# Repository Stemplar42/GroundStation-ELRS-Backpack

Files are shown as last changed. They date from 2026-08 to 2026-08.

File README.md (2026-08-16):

# GroundStation ELRS Backpack

**GroundStation ELRS Backpack** es una estación de tierra portátil basada en ESP32 para recibir y visualizar telemetría CRSF (Crossfire) desde un módulo **ExpressLRS TX Backpack** mediante WiFi/UDP.

La versión incluida en este repositorio corresponde a:

- Firmware: **GroundStation V2.5.1 Professional Stable Release**
- Release pública sugerida: **v1.0.0 Stable**
- Plataforma: **ESP32 NodeMCU 38 pines USB-C**
- Pantalla: **TFT ST7789 1,9 pulgadas, 172 x 320 píxeles**
- Autor del proyecto: **Ing. Marcelo Grippo**

GroundStation logo

## Estado del proyecto

Esta versión fue validada en hardware real con alimentación autónoma mediante una batería 18650, TP4056 y Step Down regulado a **3,30 V exactos** hacia el pin **3.3V** de la ESP32.

## Funciones principales

- Conexión automática al primer SSID visible que comience con `ExpressLRS TX Backpack xxxxxx` y luego cualquier número.
- Recepción UDP local en puerto `14550`.
- Decodificación de tramas MSPv2 y CRSF.
- Visualización de telemetría en pantalla TFT ST7789.
- Interfaz de 5 pantallas: GENERAL, HORIZONTE, ENERGIA, GPS y DEBUG.
- Horizonte artificial con pitch, roll, heading, altitud y velocidad.
- HOME automático al salir del modo `WAIT`.
- Flecha HOME tipo OSD y distancia al HOME.
- GPS con pantalla normal y modo RECOVERY.
- Código QR de recuperación hacia Google Maps cuando hay pérdida de telemetría.
- Plus Code de recuperación.
- Detección automática de cantidad de celdas de batería.
- Color por tensión por celda.
- Control de brillo PWM en GPIO `25`.
- Barra de brillo en pantalla mediante pulsación larga de NEXT.
- Botón RESET físico conectado entre EN y GND.

## Hardware principal

- ESP32 NodeMCU 38 pines USB-C.
- TFT ST7789 1,9 pulgadas 172 x 320.
- Batería Li-Ion 18650.
- Porta batería 18650.
- Módulo TP4056 con protección.
- Step Down ajustable regulado a 3,30 V.
- Interruptor general.
- Pulsadores momentáneos para NEXT, PREV y RESET.
- Gabinete impreso en 3D.

## Archivos STL del gabinete

La Release v1.0.0 documenta el gabinete final **Case V18 SMOOTH_NO_REAR_LIP**.

Los archivos STL oficiales son:

```text
stl/GroundStation_Case_Body_v18_SMOOTH_NO_REAR_LIP.stl
stl/GroundStation_Case_RearCover_v18_SMOOTH_NO_REAR_LIP.stl
```

## Conexión rápida

### Pantalla TFT ST7789

| Señal TFT | GPIO ESP32 |
|---|---:|
| MOSI / SDA | GPIO23 |
| SCLK / SCL | GPIO18 |
| CS | GPIO5 |
| DC | GPIO2 |
| RST| GPIO4|
| BL / LED | GPIO25 |
| VCC | 3.3V |
| GND | GND  |

### Botones

| Función | Conexión |
|---|---|
| PREV / ANT | GPIO32 a GND, usando `INPUT_PULLUP` |
| NEXT | GPIO33 a GND, usando `INPUT_PULLUP` |
| RESET | EN a GND mediante pulsador momentáneo |

## Alimentación recomendada

No conectar una batería 18650 directamente al pin 3.3V de la ESP32.

Conexión validada:

```text
Batería 18650 -> TP4056 -> Step Down 3,30 V -> pin 3.3V ESP32
GND común entre TP4056, Step Down, ESP32 y TFT
```

Antes de conectar la placa, ajustar la salida del Step Down con multímetro a **3,30 V exactos**.

## Instalación del firmware

1. Instalar Arduino IDE.
2. Instalar soporte para placas ESP32.
3. Instalar las librerías indicadas en `docs/04_Firmware_Setup.md`.
4. Copiar `libraries_modified/TFT_eSPI/User_Setup.h` dentro de la librería TFT_eSPI instalada.
5. Abrir `firmware/GroundStation_V2_5_1_Professional_Stable/GroundStation_V2_5_1_Professional_Stable.ino`.
6. Seleccionar la placa ESP32 correspondiente.
7. Compilar y cargar.

## Uso básico

1. Encender la GroundStation.
2. Encender el módulo ExpressLRS TX Backpack de la radio en modo WiFi.
3. Esperar que la estación encuentre el SSID `ExpressLRS TX Backpack xxxx*`.
4. Esperar recepción UDP y luego telemetría del avión (recién allí conecte el modelo).
5. Usar NEXT y PREV para navegar entre pantallas.
6. Mantener NEXT para abrir el control de brillo.
7. Usar RESET si es necesario reiniciar la ESP32.

## Documentación

- [Descripción general](docs/01_Overview.md)
- [Hardware](docs/02_Hardware.md)
- [Conexionado](docs/03_Wiring.md)
- [Instalación del firmware](docs/04_Firmware_Setup.md)
- [Manual de uso](docs/05_User_Manual.md)
- [Pantallas](docs/06_Display_Screens.md)
- [Sistema de alimentación](docs/07_Power_System.md)
- [Gabinete 3D](docs/08_3D_Case.md)
- [Solución de problemas](docs/09_Troubleshooting.md)

## Advertencia

Este proyecto es experimental y está orientado a uso maker, educativo y FPV recreativo. Verificar siempre alimentación, polaridad, cableado y estabilidad antes de utilizarlo en campo.

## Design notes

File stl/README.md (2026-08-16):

# STL files - GroundStation Case V18

The final case design for Release v1.0.0 uses the following STL files:

- `GroundStation_Case_Body_v18_SMOOTH_NO_REAR_LIP.stl`
- `GroundStation_Case_RearCover_v18_SMOOTH_NO_REAR_LIP.stl`

These STL files are not embedded in this documentation package because the chat platform did not allow uploading `.stl` or `.zip` files in the source conversation.

Before publishing the GitHub release, manually copy the two final STL files into this `stl/` folder using the exact filenames above.

## Case version

- Case version: V18
- Design variant: SMOOTH_NO_REAR_LIP
- Product release: GroundStation ELRS Backpack v1.0.0 Stable
- Firmware reference: GroundStation V2.5.1 Professional Stable Release

## Intended internal components

- ESP32 NodeMCU 38 pins USB-C
- TFT ST7789 1.9 inch display
- 18650 battery holder
- TP4056 charger module
- Step Down regulator adjusted to 3.30 V
- Main power switch
- NEXT and PREV buttons
- Physical RESET button between EN and GND

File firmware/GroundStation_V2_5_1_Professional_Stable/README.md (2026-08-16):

Firmware GroundStation V2.5.1 Professional Stable Release

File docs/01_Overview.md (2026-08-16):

<!-- GroundStation ELRS Backpack documentation -->

# 01 - Descripción general

GroundStation ELRS Backpack es una estación de tierra portátil basada en ESP32, pensada para visualizar telemetría recibida desde un módulo ExpressLRS TX Backpack.

El firmware incluido corresponde a GroundStation V2.5.1 Professional Stable Release. El sketch declara conexión WiFi contra SSID que comienzan con `ExpressLRS TX Backpack`, contraseña `expresslrs`, recepción UDP local en puerto 14550 y parser de datos MSPv2/CRSF.

## Objetivos del proyecto

- Construir una estación compacta y autónoma.
- Visualizar datos críticos de telemetría en campo.
- Mantener última posición GPS válida para recuperación.
- Ofrecer navegación por pantallas con botones físicos.
- Permitir brillo regulable para uso en exterior.
- Facilitar replicación por otros usuarios mediante documentación y archivos de firmware.

## Arquitectura general

```text
ExpressLRS TX Backpack -> WiFi -> ESP32 -> UDP 14550 -> Parser MSPv2/CRSF -> TFT ST7789
```

## Pantallas disponibles

1. GENERAL
2. HORIZONTE
3. ENERGIA
4. GPS / RECOVERY
5. DEBUG

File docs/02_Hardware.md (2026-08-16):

<!-- GroundStation ELRS Backpack documentation -->

# 02 - Hardware

## Componentes principales

- ESP32 NodeMCU 38 pines USB-C.
- Pantalla TFT ST7789 1,9 pulgadas, 172 x 320 píxeles.
- Batería Li-Ion 18650.
- Porta batería 18650.
- Módulo TP4056 con protección.
- Step Down ajustable.
- Interruptor general.
- Pulsadores momentáneos.
- Gabinete impreso en 3D.

## Pines principales extraídos del firmware

| Elemento | GPIO |
|---|---:|
| BTN_PREV | GPIO32 |
| BTN_NEXT | GPIO33 |
| Backlight PWM | GPIO25 |
| TFT MOSI | GPIO23 |
| TFT SCLK | GPIO18 |
| TFT CS | GPIO5 |
| TFT DC | GPIO2 |
| TFT RST | GPIO4 |

## Observaciones

Los botones usan `INPUT_PULLUP`, por lo tanto cada pulsador debe cerrar contra GND.

El botón RESET no está programado en el sketch porque actúa físicamente entre EN y GND.

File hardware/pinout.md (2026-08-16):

# Pinout GroundStation ELRS Backpack

## TFT ST7789

| Función | GPIO |
|---|---:|
| MOSI / SDA | GPIO23 |
| SCLK / SCL | GPIO18 |
| CS | GPIO5 |
| DC | GPIO2 |
| RST | GPIO4 |
| BL / LED / BLK | GPIO25 |

## Botones

| Función | GPIO / conexión |
|---|---|
| PREV / ANT | GPIO32 a GND |
| NEXT | GPIO33 a GND |
| RESET | EN a GND |

## Alimentación

| Señal | Conexión |
|---|---|
| +3,30 V regulados | Pin 3.3V ESP32 |
| GND | GND ESP32 |
| VCC TFT | 3.3V |
| GND TFT | GND común |

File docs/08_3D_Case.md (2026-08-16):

<!-- GroundStation ELRS Backpack documentation -->

# 08 - Gabinete 3D

## Archivos STL oficiales

La versión final del gabinete documentada para la Release v1.0.0 es:

```text
stl/
├── GroundStation_Case_Body_v18_SMOOTH_NO_REAR_LIP.stl
└── GroundStation_Case_RearCover_v18_SMOOTH_NO_REAR_LIP.stl
```

## Estado del diseño 3D

- Versión del gabinete: **V18**.
- Variante: **SMOOTH_NO_REAR_LIP**.
- Release del producto: **GroundStation ELRS Backpack v1.0.0 Stable**.
- Firmware asociado: **GroundStation V2.5.1 Professional Stable Release**.

## Filosofía de diseño

- Gabinete compacto para uso de campo.
- Diseño pensado para montaje sin tornillos.
- Fijación interna de módulos con silicona caliente.
- Tapa trasera independiente.
- Versión sin reborde posterior, indicada por `NO_REAR_LIP`.
- Acabado suavizado, indicado por `SMOOTH`.
- Pantalla frontal protegida por el propio cuerpo del gabinete.
- Espacio interno para electrónica, batería y módulos de alimentación.

## Módulos internos previstos

- ESP32 NodeMCU 38 pines USB-C.
- Pantalla TFT ST7789 de 1,9 pulgadas.
- Porta batería 18650.
- TP4056.
- Step Down regulado a 3,30 V.
- Interruptor rectangular.
- Pulsadores externos NEXT y PREV.
- Pulsador RESET físico.

## Recomendación de carpeta GitHub

Los STL finales deben ubicarse en la carpeta `stl/` del repositorio con los nombres exactos indicados arriba.

## Parámetros de impresión sugeridos

Estos valores son una base recomendada para PLA/PLA+. Pueden ajustarse según impresora, filamento y resultado buscado.

| Parámetro | Recomendación |
|---|---|
| Material | PLA o PLA+ |
| Boquilla | 0,4 mm |
| Altura de capa | 0,20 mm |
| Perímetros | 3 |
| Relleno | 15 % a 25 % |
| Patrón de relleno | Gyroid o Grid |
| Adhesión | Brim si hay riesgo de despegue |
| Soportes | Revisar en slicer según orientación elegida |
| Impresora validada por el proyecto | Artillery Sidewinder X2 |

## Orientación de impresión

La orientación debe verificarse visualmente en Cura o en el slicer utilizado. Para el cuerpo principal conviene priorizar:

- buena adherencia a la cama,
- mínima cantidad de soportes,
- buen acabado del frente de pantalla,
- resistencia adecuada en paredes y esquinas.

## Montaje recomendado

1. Imprimir el cuerpo principal y la tapa trasera.
2. Presentar la pantalla TFT en el frente antes de pegar.
3. Presentar ESP32, TP4056, Step Down y porta batería 18650.
4. Verificar acceso a conectores USB necesarios.
5. Verificar que los pulsadores accionen correctamente.
6. Fijar módulos con silicona caliente.
7. Verificar alimentación a 3,30 V antes de cerrar.
8. Cerrar la tapa trasera con silicona caliente si se desea mantener el diseño sin tornillos.

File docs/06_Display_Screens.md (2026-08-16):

<!-- GroundStation ELRS Backpack documentation -->

# 06 - Pantallas del sistema

## Pantalla de arranque

El firmware muestra una pantalla de sistema con el título `GROUND STATION`, estado `BOOTING...` y descripción `ESP32 + TFT + BACKPACK`.

## Pantalla GENERAL

Muestra modo de vuelo, tensión de batería, porcentaje de batería, LQ, SNR y satélites.

## Pantalla HORIZONTE

Muestra horizonte artificial, pitch, roll, altitud GPS, velocidad, heading, tensión de batería, flecha HOME, distancia a HOME y mini brújula.

## Pantalla ENERGIA

Muestra tensión total, detección automática de celdas, tensión por celda, corriente, consumo mAh, porcentaje INAV y potencia RF interpretada.

## Pantalla GPS

En modo normal muestra coordenadas, satélites, altitud, velocidad, heading y datos HOME.

En modo RECOVERY muestra última posición GPS válida, altitud, Plus Code y QR a Google Maps.

## Pantalla DEBUG

Muestra contadores UDP, MSPv2, CRSF, tramas AIR, paquetes desconocidos, edad de datos UDP/TEL, LQ, estado HOME, estado GPS, RF e IP local.

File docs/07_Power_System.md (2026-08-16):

<!-- GroundStation ELRS Backpack documentation -->

# 07 - Sistema de alimentación

## Esquema validado

```text
Batería 18650 -> TP4056 -> Step Down -> 3,30 V -> pin 3.3V ESP32
```

## Punto crítico

La salida del Step Down debe ajustarse con multímetro antes de conectar la ESP32. El valor validado es **3,30 V exactos**.

## Advertencias

- No conectar una batería 18650 directamente al pin 3.3V.
- Una batería 18650 completamente cargada puede estar cerca de 4,2 V.
- El pin 3.3V debe recibir una tensión regulada y estable.
- Todos los módulos deben compartir GND.
- Verificar polaridad antes de energizar.

## Recomendación de montaje

Ajustar inicialmente el Step Down sin carga, medir, conectar la ESP32, volver a medir durante funcionamiento y verificar que la tensión se mantenga estable con WiFi y TFT encendidos.

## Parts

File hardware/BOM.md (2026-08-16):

# BOM - Lista de materiales

| Ítem | Descripción | Cantidad | Observaciones |
|---|---|---:|---|
| ESP32 | NodeMCU ESP32 38 pines USB-C | 1 | Placa principal |
| Pantalla | TFT ST7789 1,9 pulgadas 172 x 320 | 1 | Display principal |
| Batería | Li-Ion 18650 | 1 | Alimentación portátil |
| Porta batería | Porta celda 18650 | 1 | Montaje interno |
| Cargador | TP4056 con protección | 1 | Carga de batería |
| Regulador | Step Down ajustable | 1 | Ajustar a 3,30 V |
| Interruptor | Interruptor rectangular con uñas | 1 | Encendido general |
| Pulsador NEXT | Pulsador momentáneo | 1 | GPIO33 a GND |
| Pulsador PREV | Pulsador momentáneo | 1 | GPIO32 a GND |
| Pulsador RESET | Pulsador momentáneo | 1 | EN a GND |
| Cableado | Cable fino flexible | varios | Conexiones internas |
| Gabinete | Impresión 3D | 1 set | Body + tapa |

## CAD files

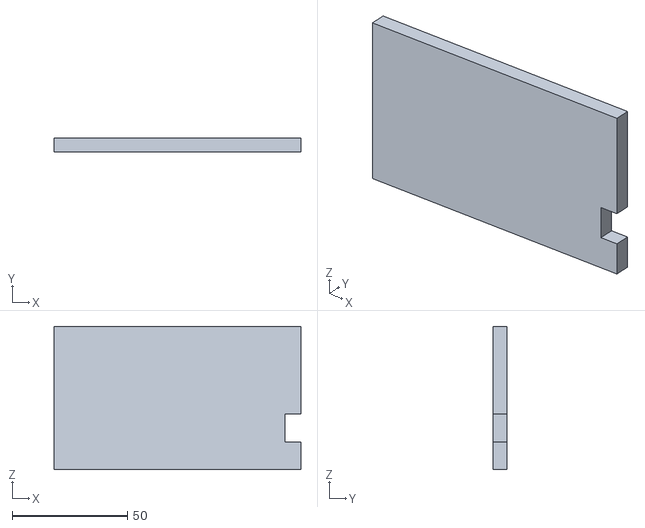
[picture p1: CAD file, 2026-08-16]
stl/GroundStation_Case_RearCover_v18_SMOOTH_NO_REAR_LIP.stl
107.0 x 6.00 x 62.0

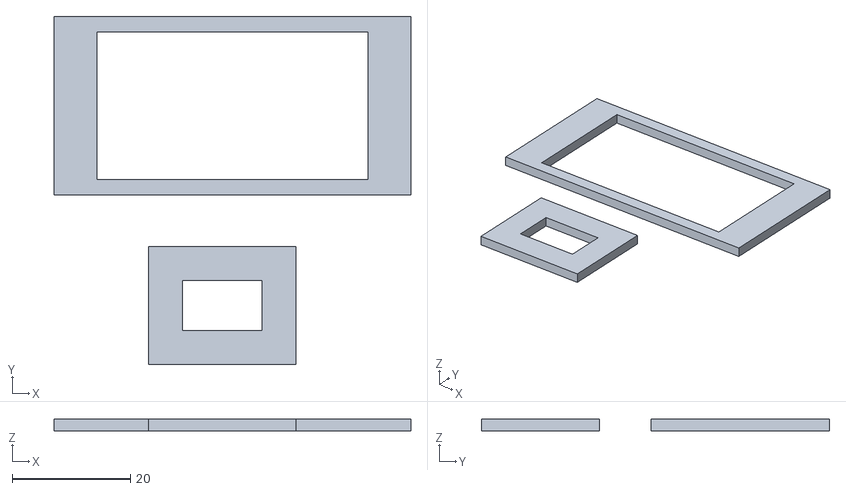
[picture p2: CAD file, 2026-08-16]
stl/Marco_ONOFF.stl
60.5 x 59.0 x 2.00

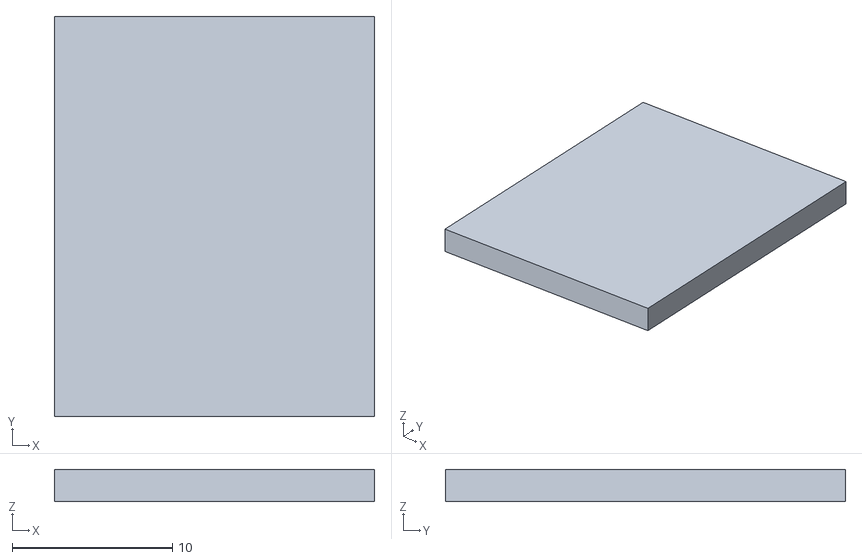
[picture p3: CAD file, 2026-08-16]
stl/Apoyo_TP4056.stl
20.0 x 25.0 x 2.00

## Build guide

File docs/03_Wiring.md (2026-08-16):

<!-- GroundStation ELRS Backpack documentation -->

# 03 - Conexionado

## Alimentación

```text
Batería 18650 positivo -> B+ TP4056
Batería 18650 negativo -> B- TP4056
OUT+ TP4056 -> entrada positiva Step Down
OUT- TP4056 -> entrada negativa Step Down
Salida Step Down +3,30 V -> pin 3.3V ESP32
Salida Step Down GND -> GND ESP32
GND común -> TFT, botones y módulos
```

## Pantalla TFT ST7789

| Pin pantalla | Conectar a ESP32 |
|---|---:|
| VCC | 3.3V |
| GND | GND |
| MOSI / SDA | GPIO23 |
| SCK / SCL | GPIO18 |
| CS | GPIO5 |
| DC | GPIO2 |
| RST | GPIO4 |
| BL / LED / BLK | GPIO25 |

## Botones

| Botón | Conexión |
|---|---|
| PREV / ANT | GPIO32 a GND |
| NEXT | GPIO33 a GND |
| RESET | EN a GND |

## Plano lógico ASCII

```text
                 +-------------------------+
                 |       ESP32 NodeMCU     |
                 |                         |
TFT MOSI --------| GPIO23                  |
TFT SCLK --------| GPIO18                  |
TFT CS ----------| GPIO5                   |
TFT DC ----------| GPIO2                   |
TFT RST ---------| GPIO4                   |
TFT BL ----------| GPIO25 PWM              |
PREV ------------| GPIO32 -> pulsador -> GND |
NEXT ------------| GPIO33 -> pulsador -> GND |
RESET -----------| EN -> pulsador -> GND   |
3.30 V ----------| 3.3V                    |
GND -------------| GND                     |
                 +-------------------------+
```

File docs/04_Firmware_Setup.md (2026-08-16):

<!-- GroundStation ELRS Backpack documentation -->

# 04 - Instalación del firmware

## Librerías utilizadas por el sketch

El sketch incluye las siguientes librerías:

- `WiFi.h`
- `WiFiUdp.h`
- `TFT_eSPI.h`
- `Preferences.h`
- `math.h`
- `qrcode.h`

## Instalación recomendada

1. Instalar Arduino IDE.
2. Instalar soporte para ESP32 desde el gestor de placas.
3. Instalar la librería TFT_eSPI.
4. Instalar o disponer de la librería `qrcode.h` compatible con ESP32.
5. Copiar `libraries_modified/TFT_eSPI/User_Setup.h` sobre el `User_Setup.h` de la librería TFT_eSPI instalada.
6. Abrir el archivo `.ino` incluido en la carpeta `firmware`.
7. Seleccionar la placa ESP32 correspondiente.
8. Compilar.
9. Cargar el firmware.

## Configuración TFT_eSPI incluida

- Driver: ST7789.
- Resolución: 172 x 320.
- MOSI: GPIO23.
- SCLK: GPIO18.
- CS: GPIO5.
- DC: GPIO2.
- RST: GPIO4.
- Frecuencia SPI: 27 MHz.

## Configuración WiFi/UDP del firmware

- Prefijo SSID: `ExpressLRS TX Backpack`.
- Contraseña: `expresslrs`.
- Puerto UDP local: `14550`.
- Timeout UDP: `2000` ms.
- Timeout telemetría de aeronave: `2000` ms.

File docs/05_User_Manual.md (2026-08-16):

<!-- GroundStation ELRS Backpack documentation -->

# 05 - Manual de uso

## Encendido

1. Colocar una batería 18650 cargada.
2. Encender el interruptor principal.
3. Confirmar que aparece la pantalla de arranque `GROUND STATION`.
4. Encender el sistema ExpressLRS TX Backpack.
5. Esperar conexión WiFi.
6. Esperar recepción UDP.
7. Esperar telemetría de aeronave.

## Navegación

| Acción | Resultado |
|---|---|
| Pulsar NEXT | Avanza a la pantalla siguiente |
| Pulsar PREV | Retrocede a la pantalla anterior |
| Mantener NEXT | Abre barra de brillo |
| NEXT en modo brillo | Sube brillo |
| PREV en modo brillo | Baja brillo |
| RESET físico | Reinicia la ESP32 |

## Niveles de brillo

El firmware define cuatro niveles PWM:

- 25 por ciento
- 50 por ciento
- 75 por ciento
- 100 por ciento

El nivel se guarda usando `Preferences`, por lo que se conserva entre reinicios.

## Estados de enlace

| Estado | Significado |
|---|---|
| LIVE | UDP y telemetría de aeronave activos |
| UDP LOST | No se reciben paquetes UDP dentro del timeout |
| TEL LOST | Hay UDP, pero no telemetría útil de la aeronave |

## Modo RECOVERY

La pantalla GPS pasa a modo RECOVERY cuando se detecta pérdida UDP o pérdida de telemetría. Si existe una última posición GPS válida, muestra coordenadas, altitud, Plus Code y QR hacia Google Maps.

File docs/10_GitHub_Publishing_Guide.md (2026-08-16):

# 10 - Guía rápida de publicación en GitHub

## Nombre sugerido del repositorio

`GroundStation-ELRS-Backpack`

## Descripción sugerida

Portable ESP32 Ground Station for ExpressLRS Backpack Telemetry.

## Antes de publicar

Verificar que estén presentes:

- `README.md`
- `CHANGELOG.md`
- `LICENSE`
- `firmware/GroundStation_V2_5_1_Professional_Stable/GroundStation_V2_5_1_Professional_Stable.ino`
- `libraries_modified/TFT_eSPI/User_Setup.h`
- `hardware/BOM.md`
- `hardware/pinout.md`
- `docs/`
- `assets/logo/groundstation_logo.svg`
- `stl/GroundStation_Case_Body_v18_SMOOTH_NO_REAR_LIP.stl`
- `stl/GroundStation_Case_RearCover_v18_SMOOTH_NO_REAR_LIP.stl`

## Release

- Tag: `v1.0.0`
- Title: `GroundStation V2.5.1 Professional Stable Release`
- Release text: copiar desde `release/GitHub_Release_Text_v1.0.0.txt`

## Recomendación

Adjuntar también este paquete ZIP como asset de la release.

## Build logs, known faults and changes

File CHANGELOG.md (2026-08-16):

# Changelog

## v1.0.0 Stable - GroundStation V2.5.1 Professional Stable Release

Primera release pública estable del proyecto GroundStation ELRS Backpack.

### Añadido

- Recepción de telemetría ExpressLRS Backpack por WiFi/UDP.
- Conexión automática al primer SSID compatible `ExpressLRS TX Backpack*`.
- Decodificación de tramas MSPv2 y CRSF.
- Pantallas GENERAL, HORIZONTE, ENERGIA, GPS y DEBUG.
- Horizonte artificial con pitch, roll, escala de alabeo y referencia de aeronave.
- HOME automático al detectar modo de vuelo distinto de `WAIT` con GPS válido.
- Flecha HOME tipo OSD.
- Mini brújula.
- Pantalla GPS estilo instrumento con coordenadas, satélites, altitud, velocidad y rumbo.
- Modo RECOVERY con última posición GPS válida.
- QR de recuperación para Google Maps.
- Plus Code de recuperación.
- Detección automática de celdas 2S a 8S.
- Color por tensión por celda.
- Control de brillo PWM en backlight.
- Persistencia de brillo en memoria Preferences.
- Botón RESET físico por EN a GND.

### Corregido

- Brillo PWM corregido y estable.
- Barra de brillo con actualización en vivo.
- Reset físico sin necesidad de lógica adicional en firmware.
- Conservación de última posición GPS válida durante pérdida de telemetría.

### Validado

- ESP32 NodeMCU 38 pines USB-C.
- TFT ST7789 1,9 pulgadas 172 x 320.
- Alimentación por batería 18650 con Step Down ajustado a 3,30 V.
- Funcionamiento de navegación por botones y control de brillo.

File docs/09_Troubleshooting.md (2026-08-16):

<!-- GroundStation ELRS Backpack documentation -->

# 09 - Solución de problemas

## La ESP32 no enciende

- Comprobar batería 18650.
- Comprobar interruptor.
- Medir salida del Step Down.
- Confirmar 3,30 V en el pin 3.3V.
- Confirmar GND común.

## La pantalla no muestra imagen

- Verificar VCC y GND de la TFT.
- Verificar MOSI, SCLK, CS, DC y RST.
- Confirmar que la pantalla sea ST7789 172 x 320.
- Confirmar instalación correcta del `User_Setup.h` incluido.

## El brillo no cambia

- Verificar que BL/LED/BLK de la pantalla vaya a GPIO25.
- Verificar soldadura del pin de backlight.
- Mantener NEXT para abrir modo brillo.

## No conecta al Backpack

- Confirmar que el SSID comience con `ExpressLRS TX Backpack`.
- Confirmar contraseña `expresslrs`.
- Reiniciar Backpack y GroundStation.
- Acercar la estación al transmisor.

## UDP LOST

- Indica que no llegaron paquetes UDP dentro del timeout.
- Verificar WiFi y Backpack.

## TEL LOST

- Indica que hay UDP, pero no telemetría útil de aeronave dentro del timeout.
- Verificar que el avión transmita datos CRSF/MSPv2.

## Lecturas GPS nulas

- Esperar al menos 4 satélites.
- Verificar que el GPS del avión tenga fix.
- Verificar que la telemetría esté llegando correctamente.

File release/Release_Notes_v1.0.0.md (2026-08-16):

# Release v1.0.0 Stable

## GroundStation V2.5.1 Professional Stable Release

Primera publicación estable del proyecto GroundStation ELRS Backpack.

## Incluye

- Firmware Arduino IDE completo.
- Configuración TFT_eSPI adaptada a ST7789 172 x 320.
- Documentación de hardware.
- Pinout.
- Manual de usuario.
- Sistema de alimentación recomendado.
- Solución de problemas.
- Logo SVG del proyecto.

## Funciones destacadas

- Telemetría ELRS Backpack por WiFi/UDP.
- Parser MSPv2/CRSF.
- Horizonte artificial.
- HOME automático.
- GPS RECOVERY con QR.
- Control de brillo PWM.
- Botón RESET físico.
- Alimentación autónoma con 18650.

## Gabinete 3D incluido en la documentación

La release queda preparada para incluir los STL finales del gabinete:

- `GroundStation_Case_Body_v18_SMOOTH_NO_REAR_LIP.stl`
- `GroundStation_Case_RearCover_v18_SMOOTH_NO_REAR_LIP.stl`

Estos archivos corresponden al **Case V18 SMOOTH_NO_REAR_LIP**. Si los STL no están dentro del ZIP, copiarlos manualmente a la carpeta `stl/` antes de publicar en GitHub.

## Advertencia

Uso experimental. Verificar cableado, polaridad y alimentación antes de energizar.

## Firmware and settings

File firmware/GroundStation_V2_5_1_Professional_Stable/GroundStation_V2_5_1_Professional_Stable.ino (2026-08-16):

#include <WiFi.h>
#include <WiFiUdp.h>
#include <TFT_eSPI.h>
#include <Preferences.h>
#include <math.h>
#include <qrcode.h>

// =====================================================
// GROUND STATION V2.5.1
// ESP32 + ExpressLRS Backpack WiFi + CRSF + ST7789 TFT
// Base V2.4.2 recuperada + brillo PWM corregido + reset EN
// =====================================================
//
// Basada en GroundStation V2.1 validada.
// Cambios V2.3:
// - HOME automatico al salir de modo WAIT.
// - Distancia y rumbo al HOME.
// - Flecha HOME tipo OSD en pantalla Horizonte.
// - Altitud y velocidad en pantalla Horizonte.
// - Mini brujula N/E/S/W en pantalla Horizonte.
// - Pantalla POWER con deteccion automatica de celdas y V/Celda por color.
// - Pantalla GPS con estilo mas tipo Garmin.
// - Plus Code en pantalla RECOVERY.
// - QR de recuperacion solo en TEL LOST / UDP LOST.
// - Conexion automatica al primer SSID ExpressLRS TX Backpack visible.
// - QR compatible con libreria Espressif qrcode.h.
// - Brillo PWM en BLK por GPIO25.
// - Pulsacion larga NEXT abre barra de brillo.
// - En modo brillo: NEXT sube, PREV baja, barra actualiza en vivo.
// - Boton RESET dedicado: EN a GND.
// - No se modifica Core CRSF / UDP / Backpack / estados.
// =====================================================

// =====================================================
// WIFI BACKPACK
// =====================================================

const char* BACKPACK_PREFIX = "ExpressLRS TX Backpack";
const char* password = "expresslrs";

String selectedBackpackSsid = "";

WiFiUDP udp;

#define UDP_PORT_LOCAL 14550
#define TIMEOUT_UDP_MS 2000
#define TIMEOUT_AIRCRAFT_TELEM_MS 2000

// =====================================================
// BOTONES
// =====================================================

#define BTN_PREV 32
#define BTN_NEXT 33

// =====================================================
// BRILLO PWM / RESET
// =====================================================
// GPIO25 debe ir al pin BLK / BL / BACKLIGHT del TFT.
// El boton RESET fisico va entre EN y GND. No requiere codigo.

#define PIN_BL 25
#define BL_PWM_FREQ 5000
#define BL_PWM_RES 8
#define BL_PWM_CH 0

const uint8_t BRIGHTNESS_LEVELS[] = {64, 128, 192, 255};
const int BRIGHTNESS_COUNT = 4;
int brightnessIndex = 3;
uint32_t brightnessOverlayUntilMs = 0;
Preferences prefs;

// =====================================================
// TFT / SPRITE
// =====================================================

TFT_eSPI tft = TFT_eSPI();
TFT_eSprite spr = TFT_eSprite(&tft);

const int SCREEN_W = 320;
const int SCREEN_H = 172;

const int SPR_W = 320;
const int SPR_H = 172;

// Horizonte artificial
const int CX = 160;
const int CY = 92;
const int R  = 68;

const float PITCH_PIXELS_PER_DEG = 2.0;

// =====================================================
// PANTALLAS
// =====================================================

enum PantallaGS {
  P_GENERAL = 0,
  P_HORIZONTE = 1,
  P_ENERGIA = 2,
  P_GPS = 3,
  P_DEBUG = 4
};

const int TOTAL_PANTALLAS = 5;
int pantallaActual = P_GENERAL;

// =====================================================
// ESTADOS
// =====================================================

bool tuvoPrimerUdp = false;
bool tuvoPrimerAircraftTelemetry = false;

// =====================================================
// HOME AUTOMATICO
// =====================================================

bool homeSet = false;
double homeLat = 0.0;
double homeLon = 0.0;
uint32_t homeSetMs = 0;

float homeDistanceM = 0.0;
float homeBearingDeg = 0.0;
float homeRelativeBearingDeg = 0.0;

bool lastGoodGpsSet = false;
double lastGoodLat = 0.0;
double lastGoodLon = 0.0;
int lastGoodAlt = 0;
uint32_t lastGoodGpsMs = 0;

int qrDrawX = 0;
int qrDrawY = 0;
int qrDrawScale = 2;

// =====================================================
// COLORES
// =====================================================

uint16_t SKY_COLOR;
uint16_t GROUND_COLOR;
uint16_t WHITE_COLOR;
uint16_t YELLOW_COLOR;
uint16_t CYAN_COLOR;
uint16_t ORANGE_COLOR;
uint16_t RED_COLOR;
uint16_t GREEN_COLOR;
uint16_t DARKGREY_COLOR;

// =====================================================
// ESTRUCTURA DE TELEMETRIA
// =====================================================

struct Telemetria {
  bool wifiConectado;
  bool recibeDatos;

  String modoVuelo;

  float voltaje;
  float corriente;
  uint32_t consumoMah;
  int bateriaRestante;

  int uplinkLQ;
  int downlinkLQ;

  int uplinkSNR;
  int downlinkSNR;

  int rfPowerEnum;
  String rfPowerTexto;

  float pitch;
  float roll;
  float yaw;

  double lat;
  double lon;
  float gpsSpeed;
  float gpsHeading;
  int gpsAltitude;
  int sats;

  float baroAltitude;
  float verticalSpeed;

  uint32_t paquetesUdp;
  uint32_t tramasMspV2;
  uint32_t tramasCrsf;
  uint32_t tramasTelemetriaAvion;
  uint32_t paquetesDesconocidos;

  uint32_t ultimoUdpMs;
  uint32_t ultimoCrsfMs;
  uint32_t ultimaTelemetriaAvionMs;
};

Telemetria tel;

// =====================================================
// INICIALIZACION TELEMETRIA
// =====================================================

void inicializarTelemetria()
{
  tel.wifiConectado = false;
  tel.recibeDatos = false;

  tel.modoVuelo = "---";

  tel.voltaje = 0.0;
  tel.corriente = 0.0;
  tel.consumoMah = 0;
  tel.bateriaRestante = -1;

  tel.uplinkLQ = -1;
  tel.downlinkLQ = -1;

  tel.uplinkSNR = 0;
  tel.downlinkSNR = 0;

  tel.rfPowerEnum = -1;
  tel.rfPowerTexto = "---";

  tel.pitch = 0.0;
  tel.roll = 0.0;
  tel.yaw = 0.0;

  tel.lat = 0.0;
  tel.lon = 0.0;
  tel.gpsSpeed = 0.0;
  tel.gpsHeading = 0.0;
  tel.gpsAltitude = 0;
  tel.sats = 0;

  tel.baroAltitude = 0.0;
  tel.verticalSpeed = 0.0;

  tel.paquetesUdp = 0;
  tel.tramasMspV2 = 0;
  tel.tramasCrsf = 0;
  tel.tramasTelemetriaAvion = 0;
  tel.paquetesDesconocidos = 0;

  tel.ultimoUdpMs = 0;
  tel.ultimoCrsfMs = 0;
  tel.ultimaTelemetriaAvionMs = 0;
}

// =====================================================
// FUNCIONES DE LECTURA BINARIA
// =====================================================

uint16_t readU16LE(const uint8_t* p)
{
  return (uint16_t)p[0] | ((uint16_t)p[1] << 8);
}

uint16_t readU16BE(const uint8_t* p)
{
  return ((uint16_t)p[0] << 8) | (uint16_t)p[1];
}

int16_t readS16BE(const uint8_t* p)
{
  return (int16_t)readU16BE(p);
}

uint32_t readU24BE(const uint8_t* p)
{
  return ((uint32_t)p[0] << 16) |
         ((uint32_t)p[1] << 8)  |
         (uint32_t)p[2];
}

int32_t readS32BE(const uint8_t* p)
{
  uint32_t v =
    ((uint32_t)p[0] << 24) |
    ((uint32_t)p[1] << 16) |
    ((uint32_t)p[2] << 8)  |
    (uint32_t)p[3];

  return (int32_t)v;
}

// =====================================================
// MAPEO POTENCIA RF
// =====================================================

String mapRfPower(uint8_t rfPowerEnum)
{
  switch (rfPowerEnum) {
    case 0: return "10mW?";
    case 1: return "10/25?";
    case 2: return "25mW";
    case 3: return "50/100?";
    case 4: return "250mW?";
    case 5: return "500mW?";
    case 6: return "1000mW?";
    default: return "Enum " + String(rfPowerEnum);
  }
}

// =====================================================
// IDENTIFICACION DE TRAMAS DE TELEMETRIA DEL AVION
// =====================================================

bool esTramaTelemetriaAvion(uint8_t type)
{
  switch (type) {
    case 0x02: // GPS
    case 0x07: // VARIOMETER
    case 0x08: // BATTERY
    case 0x09: // BARO ALTITUDE
    case 0x1E: // ATTITUDE
    case 0x21: // FLIGHT MODE
      return true;

    default:
      return false;
  }
}

// =====================================================
// DECODIFICADORES CRSF
// =====================================================

void decodeFlightMode(const uint8_t* payload, int payloadLen)
{
  String modo = "";

  for (int i = 0; i < payloadLen; i++) {
    char c = (char)payload[i];

    if (c == 0) break;

    if (c >= 32 && c <= 126) {
      modo += c;
    }
  }

  if (modo.length() > 0) {
    tel.modoVuelo = modo;
  }
}

void decodeLinkStatistics(const uint8_t* p, int len)
{
  if (len < 10) return;

  uint8_t upLq    = p[2];
  int8_t  upSnr   = (int8_t)p[3];
  uint8_t rfPower = p[6];
  uint8_t downLq  = p[8];
  int8_t  downSnr = (int8_t)p[9];

  tel.uplinkLQ = upLq;
  tel.uplinkSNR = upSnr;

  tel.downlinkLQ = downLq;
  tel.downlinkSNR = downSnr;

  tel.rfPowerEnum = rfPower;
  tel.rfPowerTexto = mapRfPower(rfPower);
}

void decodeAttitude(const uint8_t* p, int len)
{
  if (len < 6) return;

  int16_t pitchRaw = readS16BE(p + 0);
  int16_t rollRaw  = readS16BE(p + 2);
  int16_t yawRaw   = readS16BE(p + 4);

  tel.pitch = -pitchRaw * 0.00572958f;
  tel.roll  = -rollRaw  * 0.00572958f;
  tel.yaw   = yawRaw   * 0.00572958f;
}

void decodeBattery(const uint8_t* p, int len)
{
  if (len < 8) return;

  uint16_t voltageRaw = readU16BE(p + 0);
  uint16_t currentRaw = readU16BE(p + 2);
  uint32_t capacityMah = readU24BE(p + 4);
  uint8_t remaining = p[7];

  tel.voltaje = voltageRaw / 10.0f;
  tel.corriente = currentRaw / 10.0f;
  tel.consumoMah = capacityMah;
  tel.bateriaRestante = remaining;
}

void decodeBaroAltitude(const uint8_t* p, int len)
{
  if (len < 2) return;

  uint16_t rawAlt = readU16BE(p);

  if (rawAlt == 0xFFFF) return;

  if ((rawAlt & 0x8000) == 0) {
    tel.baroAltitude = ((int32_t)rawAlt - 10000) / 10.0f;
  }
  else {
    tel.baroAltitude = rawAlt & 0x7FFF;
  }

  if (len >= 3) {
    int8_t vsRaw = (int8_t)p[2];
    tel.verticalSpeed = vsRaw * 0.03f;
  }
}

void decodeVariometer(const uint8_t* p, int len)
{
  if (len < 2) return;

  int16_t raw = readS16BE(p);
  tel.verticalSpeed = raw / 100.0f;
}

void decodeGpsBasic(const uint8_t* p, int len)
{
  if (len < 15) return;

  int32_t latRaw = readS32BE(p + 0);
  int32_t lonRaw = readS32BE(p + 4);
  uint16_t groundSpeedRaw = readU16BE(p + 8);
  uint16_t headingRaw = readU16BE(p + 10);
  uint16_t altitudeRaw = readU16BE(p + 12);
  uint8_t satellites = p[14];

  tel.lat = latRaw / 10000000.0;
  tel.lon = lonRaw / 10000000.0;
  tel.gpsSpeed = groundSpeedRaw / 100.0f;
  tel.gpsHeading = headingRaw / 100.0f;
  tel.gpsAltitude = (int)altitudeRaw - 1000;
  tel.sats = satellites;

  if (satellites >= 4 && fabs(tel.lat) > 0.000001 && fabs(tel.lon) > 0.000001) {
    lastGoodLat = tel.lat;
    lastGoodLon = tel.lon;
    lastGoodAlt = tel.gpsAltitude;
    lastGoodGpsMs = millis();
    lastGoodGpsSet = true;
  }
}

// =====================================================
// PARSER CRSF
// =====================================================

bool decodeCrsfFrame(const uint8_t* crsf, int crsfLenTotal)
{
  if (crsfLenTotal < 4) return false;

  uint8_t frameLen = crsf[1];

  if (frameLen < 2 || frameLen > 62) return false;

  int expectedTotal = frameLen + 2;

  if (expectedTotal > crsfLenTotal) return false;

  uint8_t type = crsf[2];

  const uint8_t* payload = crsf + 3;
  int payloadLen = frameLen - 2;

  tel.tramasCrsf++;
  tel.ultimoCrsfMs = millis();

  if (esTramaTelemetriaAvion(type)) {
    tel.ultimaTelemetriaAvionMs = millis();
    tel.tramasTelemetriaAvion++;
    tel.recibeDatos = true;
    tuvoPrimerAircraftTelemetry = true;
  }

  switch (type) {
    case 0x02:
      decodeGpsBasic(payload, payloadLen);
      break;

    case 0x07:
      decodeVariometer(payload, payloadLen);
      break;

    case 0x08:
      decodeBattery(payload, payloadLen);
      break;

    case 0x09:
      decodeBaroAltitude(payload, payloadLen);
      break;

    case 0x14:
      decodeLinkStatistics(payload, payloadLen);
      break;

    case 0x1E:
      decodeAttitude(payload, payloadLen);
      break;

    case 0x21:
      decodeFlightMode(payload, payloadLen);
      break;

    default:
      break;
  }

  return true;
}

// =====================================================
// PARSER MSPv2
// =====================================================

bool parseMspV2Frames(const uint8_t* data, int len)
{
  bool encontro = false;
  int pos = 0;

  while (pos <= len - 9) {
    if (data[pos] == '$' && data[pos + 1] == 'X') {

      uint16_t function = readU16LE(data + pos + 4);
      uint16_t payloadSize = readU16LE(data + pos + 6);

      int totalMspLen = 8 + payloadSize + 1;

      if (payloadSize > 512) {
        pos++;
        continue;
      }

      if (pos + totalMspLen > len) {
        return encontro;
      }

      const uint8_t* payload = data + pos + 8;

      tel.tramasMspV2++;
      encontro = true;

      if (function == 17) {
        decodeCrsfFrame(payload, payloadSize);
      }

      pos += totalMspLen;
    }
    else {
      pos++;
    }
  }

  return encontro;
}

// =====================================================
// PROCESADOR UDP
// =====================================================

void procesarPaqueteUdp(const uint8_t* data, int len)
{
  bool interpretado = false;

  if (parseMspV2Frames(data, len)) {
    interpretado = true;
  }

  if (!interpretado) {
    tel.paquetesDesconocidos++;
  }
}

void leerUdp()
{
  int packetSize = udp.parsePacket();

  if (packetSize > 0) {
    uint8_t buffer[768];

    int len = udp.read(buffer, sizeof(buffer));

    tel.paquetesUdp++;
    tel.ultimoUdpMs = millis();

    tuvoPrimerUdp = true;

    procesarPaqueteUdp(buffer, len);
  }

  if (tuvoPrimerAircraftTelemetry &&
      millis() - tel.ultimaTelemetriaAvionMs > TIMEOUT_AIRCRAFT_TELEM_MS) {
    tel.recibeDatos = false;
  }
}

// =====================================================
// ESTADO DE ENLACES
// =====================================================

bool udpOk()
{
  if (!tuvoPrimerUdp) return false;
  return (millis() - tel.ultimoUdpMs) <= TIMEOUT_UDP_MS;
}

bool aircraftTelemetryOk()
{
  if (!tuvoPrimerAircraftTelemetry) return false;
  return (millis() - tel.ultimaTelemetriaAvionMs) <= TIMEOUT_AIRCRAFT_TELEM_MS;
}

uint32_t udpAgeSec()
{
  if (!tuvoPrimerUdp) return 0;
  return (millis() - tel.ultimoUdpMs) / 1000;
}

uint32_t aircraftTelemetryAgeSec()
{
  if (!tuvoPrimerAircraftTelemetry) return 0;
  return (millis() - tel.ultimaTelemetriaAvionMs) / 1000;
}

// =====================================================
// HOME / NAVEGACION
// =====================================================

double degToRadD(double deg)
{
  return deg * 3.14159265358979323846 / 180.0;
}

double radToDegD(double rad)
{
  return rad * 180.0 / 3.14159265358979323846;
}

float normalize360(float deg)
{
  while (deg < 0.0f) deg += 360.0f;
  while (deg >= 360.0f) deg -= 360.0f;
  return deg;
}

float normalize180(float deg)
{
  deg = normalize360(deg);
  if (deg > 180.0f) deg -= 360.0f;
  return deg;
}

// =====================================================
// DETECCION AUTOMATICA DE CELDAS / VOLTAJE POR CELDA
// =====================================================

int detectarCeldas(float voltaje)
{
  if (voltaje < 5.0f)  return 0;
  if (voltaje <= 8.8f)  return 2;  // 2S
  if (voltaje <= 13.2f) return 3;  // 3S
  if (voltaje <= 17.6f) return 4;  // 4S
  if (voltaje <= 22.0f) return 5;  // 5S
  if (voltaje <= 26.4f) return 6;  // 6S
  if (voltaje <= 30.8f) return 7;  // 7S
  if (voltaje <= 35.2f) return 8;  // 8S
  return 0;
}

float voltajePorCelda()
{
  int celdas = detectarCeldas(tel.voltaje);

  if (celdas <= 0) {
    return 0.0f;
  }

  return tel.voltaje / celdas;
}

uint16_t colorVoltajeCelda()
{
  float vCell = voltajePorCelda();

  if (vCell >= 4.10f) return TFT_GREEN;
  if (vCell >= 3.80f) return TFT_YELLOW;
  if (vCell >= 3.60f) return TFT_ORANGE;

  return TFT_RED;
}

bool gpsValidoParaHome()
{
  if (tel.sats < 4) return false;
  if (fabs(tel.lat) < 0.000001 && fabs(tel.lon) < 0.000001) return false;
  return true;
}

bool modeloArmadoPorModo()
{
  if (tel.modoVuelo.length() == 0) return false;
  if (tel.modoVuelo == "---") return false;
  if (tel.modoVuelo == "WAIT") return false;
  return true;
}

float headingActual()
{
  if (tel.gpsHeading > 0.5f) {
    return normalize360(tel.gpsHeading);
  }
  return normalize360(tel.yaw);
}

float calcularDistanciaM(double lat1, double lon1, double lat2, double lon2)
{
  const double Rearth = 6371000.0;
  double phi1 = degToRadD(lat1);
  double phi2 = degToRadD(lat2);
  double dPhi = degToRadD(lat2 - lat1);
  double dLambda = degToRadD(lon2 - lon1);

  double a = sin(dPhi / 2.0) * sin(dPhi / 2.0) +
             cos(phi1) * cos(phi2) *
             sin(dLambda / 2.0) * sin(dLambda / 2.0);

  double c = 2.0 * atan2(sqrt(a), sqrt(1.0 - a));
  return (float)(Rearth * c);
}

float calcularBearingDeg(double lat1, double lon1, double lat2, double lon2)
{
  double phi1 = degToRadD(lat1);
  double phi2 = degToRadD(lat2);
  double dLambda = degToRadD(lon2 - lon1);

  double y = sin(dLambda) * cos(phi2);
  double x = cos(phi1) * sin(phi2) -
             sin(phi1) * cos(phi2) * cos(dLambda);

  double brng = radToDegD(atan2(y, x));
  return normalize360((float)brng);
}

void actualizarHome()
{
  if (!homeSet && modeloArmadoPorModo() && gpsValidoParaHome()) {
    homeLat = tel.lat;
    homeLon = tel.lon;
    homeSet = true;
    homeSetMs = millis();
  }

  if (homeSet && gpsValidoParaHome()) {
    homeDistanceM = calcularDistanciaM(tel.lat, tel.lon, homeLat, homeLon);
    homeBearingDeg = calcularBearingDeg(tel.lat, tel.lon, homeLat, homeLon);
    homeRelativeBearingDeg = normalize180(homeBearingDeg - headingActual());
  }
}

String generarPlusCode(double lat, double lon)
{
  const char* alphabet = "23456789CFGHJMPQRVWX";

  if (lat < -90.0) lat = -90.0;
  if (lat >= 90.0) lat = 90.0 - 0.000000001;

  while (lon < -180.0) lon += 360.0;
  while (lon >= 180.0) lon -= 360.0;

  long latVal = (long)floor((lat + 90.0) * 8000.0);
  long lonVal = (long)floor((lon + 180.0) * 8000.0);

  long divisors[5] = {160000, 8000, 400, 20, 1};
  String code = "";

  for (int i = 0; i < 5; i++) {
    int latDigit = (latVal / divisors[i]) % 20;
    int lonDigit = (lonVal / divisors[i]) % 20;
    code += alphabet[latDigit];
    code += alphabet[lonDigit];
    if (i == 3) code += "+";
  }

  return code;
}

String plusCodeRecuperacion()
{
  if (lastGoodGpsSet) {
    return generarPlusCode(lastGoodLat, lastGoodLon);
  }
  return generarPlusCode(tel.lat, tel.lon);
}

String generarUrlGpsRecuperacion()
{
  String url = "https://maps.google.com/?q=";
  if (lastGoodGpsSet) {
    url += String(lastGoodLat, 7);
    url += ",";
    url += String(lastGoodLon, 7);
  }
  else {
    url += String(tel.lat, 7);
    url += ",";
    url += String(tel.lon, 7);
  }
  return url;
}

void qrDisplayCallback(esp_qrcode_handle_t qrcode)
{
  int size = esp_qrcode_get_size(qrcode);
  const int quiet = 2;
  int totalModules = size + quiet * 2;
  int qrPx = totalModules * qrDrawScale;

  spr.fillRect(qrDrawX, qrDrawY, qrPx, qrPx, TFT_WHITE);

  for (int y = 0; y < size; y++) {
    for (int x = 0; x < size; x++) {
      if (esp_qrcode_get_module(qrcode, x, y)) {
        spr.fillRect(qrDrawX + (x + quiet) * qrDrawScale,
                     qrDrawY + (y + quiet) * qrDrawScale,
                     qrDrawScale,
                     qrDrawScale,
                     TFT_BLACK);
      }
    }
  }
  spr.drawRect(qrDrawX, qrDrawY, qrPx, qrPx, TFT_DARKGREY);
}

void drawRecoveryQr(int x0, int y0, int escala)
{
  if (!lastGoodGpsSet) {
    spr.fillRect(x0, y0, 76, 76, TFT_BLACK);
    spr.drawRect(x0, y0, 76, 76, TFT_DARKGREY);
    spr.setTextDatum(MC_DATUM);
    spr.setTextSize(1);
    spr.setTextColor(TFT_DARKGREY, TFT_BLACK);
    spr.drawString("NO GPS", x0 + 38, y0 + 30);
    spr.drawString("QR", x0 + 38, y0 + 45);
    return;
  }

  qrDrawX = x0;
  qrDrawY = y0;
  qrDrawScale = escala;

  String qrText = generarUrlGpsRecuperacion();

  esp_qrcode_config_t cfg = ESP_QRCODE_CONFIG_DEFAULT();
  cfg.display_func = qrDisplayCallback;
  cfg.max_qrcode_version = 5;
  cfg.qrcode_ecc_level = ESP_QRCODE_ECC_LOW;

  esp_qrcode_generate(&cfg, qrText.c_str());
}

// =====================================================
// BACKLIGHT PWM / BARRA DE BRILLO
// =====================================================

void backlightPwmAttach()
{
#if defined(ESP_ARDUINO_VERSION_MAJOR) && ESP_ARDUINO_VERSION_MAJOR >= 3
  ledcAttach(PIN_BL, BL_PWM_FREQ, BL_PWM_RES);
#else
  ledcSetup(BL_PWM_CH, BL_PWM_FREQ, BL_PWM_RES);
  ledcAttachPin(PIN_BL, BL_PWM_CH);
#endif
}

void backlightPwmWrite(uint8_t value)
{
#if defined(ESP_ARDUINO_VERSION_MAJOR) && ESP_ARDUINO_VERSION_MAJOR >= 3
  ledcWrite(PIN_BL, value);
#else
  ledcWrite(BL_PWM_CH, value);
#endif
}

void cargarBrillo()
{
  prefs.begin("gs", false);
  brightnessIndex = prefs.getInt("bright", 3);

  if (brightnessIndex < 0 || brightnessIndex >= BRIGHTNESS_COUNT) {
    brightnessIndex = 3;
  }
}

void guardarBrillo()
{
  prefs.putInt("bright", brightnessIndex);
}

int brilloPorcentaje()
{
  switch (brightnessIndex) {
    case 0: return 25;
    case 1: return 50;
    case 2: return 75;
    default: return 100;
  }
}

void aplicarBrillo()
{
  backlightPwmWrite(BRIGHTNESS_LEVELS[brightnessIndex]);
}

bool mostrarOverlayBrillo()
{
  return millis() < brightnessOverlayUntilMs;
}

void abrirModoBrillo()
{
  brightnessOverlayUntilMs = millis() + 5000;
}

void cambiarBrillo(int delta)
{
  brightnessIndex += delta;

  if (brightnessIndex < 0) brightnessIndex = 0;
  if (brightnessIndex >= BRIGHTNESS_COUNT) brightnessIndex = BRIGHTNESS_COUNT - 1;

  aplicarBrillo();
  guardarBrillo();
  brightnessOverlayUntilMs = millis() + 5000;
}
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
void loop()
{
  leerUdp();
  actualizarHome();
  leerBotones();

  static uint32_t lastDraw = 0;

  if (millis() - lastDraw > 80) {
    lastDraw = millis();

    if (mostrarOverlayBrillo()) {
      drawBrightnessOverlay();
    }
    else if (!tuvoPrimerUdp) {
      drawWaitingUdpScreen();
    }
    else if (!tuvoPrimerAircraftTelemetry) {
      drawWaitingAircraftTelemetryScreen();
    }
    else {
      drawPantallaActual();
    }
  }
}

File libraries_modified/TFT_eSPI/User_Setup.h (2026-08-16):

// User_Setup.h - GroundStation ELRS Backpack
// TFT_eSPI custom configuration validated for Marcelo Grippo GroundStation V2.5.1
// Display: ST7789 1.9 inch, 172 x 320, used in landscape rotation by firmware.

#define USER_SETUP_INFO "GroundStation_ELRS_Backpack_ST7789_172x320"

#define ST7789_DRIVER
#define CGRAM_OFFSET

#define TFT_WIDTH  172
#define TFT_HEIGHT 320

// SPI display pins for ESP32 NodeMCU 38-pin board
#define TFT_MOSI 23
#define TFT_SCLK 18
#define TFT_CS    5
#define TFT_DC    2
#define TFT_RST   4

// Backlight is controlled from the sketch using PWM on GPIO25.
// Do not enable TFT_BL here unless you intentionally move brightness control into TFT_eSPI.
// #define TFT_BL 25
// #define TFT_BACKLIGHT_ON HIGH

// Fonts used by the project
#define LOAD_GLCD
#define LOAD_FONT2
#define LOAD_FONT4
#define LOAD_FONT6
#define LOAD_FONT7
#define LOAD_FONT8
#define LOAD_GFXFF
#define SMOOTH_FONT

// SPI speed validated with the selected ST7789 display
#define SPI_FREQUENCY       27000000
#define SPI_READ_FREQUENCY  20000000
#define SPI_TOUCH_FREQUENCY 2500000

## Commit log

2026-08-16 Initial release GroundStation V2.5.1 Professional Stable
    [Apoyo_TP4056.stl]
2026-08-16 Add README for GroundStation V2.5.1 release
    Firmware GroundStation V2.5.1 Professional Stable Release
2026-08-16 Delete note about STL file attachment for publication
    Removed publication note regarding STL files.
